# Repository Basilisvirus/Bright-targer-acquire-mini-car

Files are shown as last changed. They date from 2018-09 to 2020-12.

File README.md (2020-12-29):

# Bright-targer-acquire-mini-car
This project is written in greek.

A mini battery-runned car that avoids obstacles and follows the brighter light-emitting source simultaneously. 

https://drive.google.com/open?id=1Uj9xmuziskHSL8KATfDlSYlBZ7Kqk1FP

Having any issues with the project? email me: christianidis@disroot.org

Κατασκέυασα & προγραμμάτισα αυτοκινούμενο μικρό όχημα η κίνηση του οποίου ελέγχεται από  μικρουπολογιστή atmega328p. Αποφεύγει εμπόδια και ταυτόχρονα κινειται στη πιο φωτεινή πηγή

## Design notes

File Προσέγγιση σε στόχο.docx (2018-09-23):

Manual…………………………………………………….………….6

# Christianidis Vasileios

# basilisvirus@hotmail.com

# Η κατασκευή

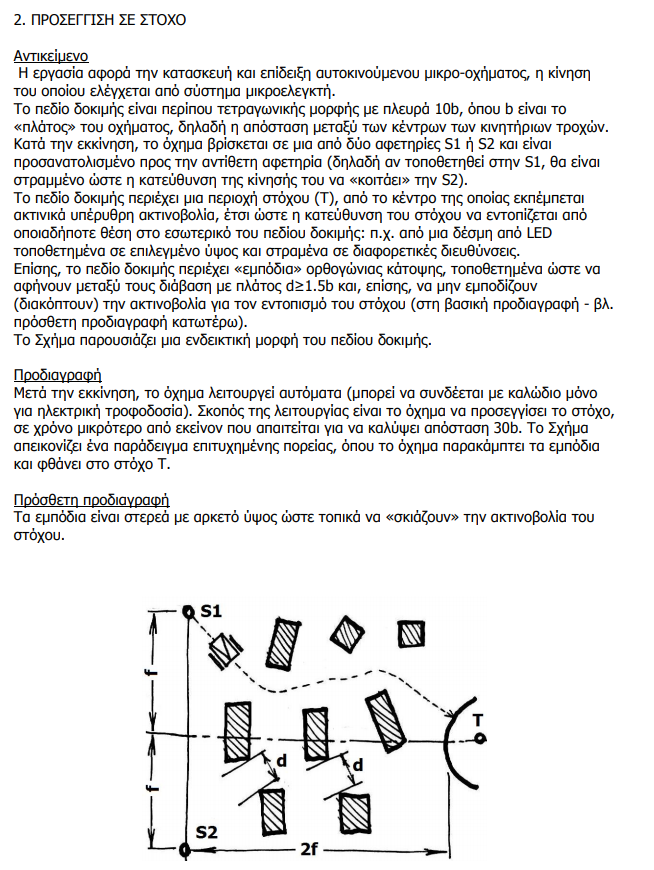
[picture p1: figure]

# Hardware

Σημείωση: δε θα παραθέτω links για datasheetsσε αυτό το αρχείο.

- Ο κώδικας, το schematic και τα sources μπορουν να βρεθούν εδώ: https://1drv.ms/f/s!Amo8HTWu_uS8hRjVVsb1Y_wef7Os αλλά θα παρασταθούν και σε αυτο το document.
- Για το σασί χρησιμοποιήθηκαν τα 3d printed open source σχέδια από αυτή την ιστοσελίδα: https://www.thingiverse.com/thing:739024/#files
- Για ρόδες, μαζί με 4 dc motors with gears χρησιμοποιήθηκαν:

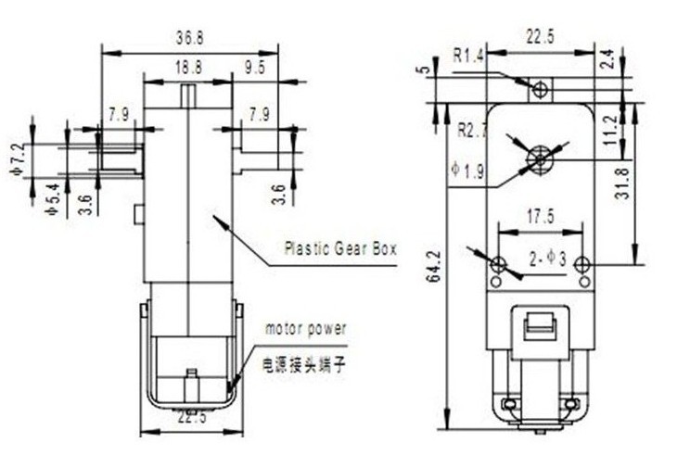
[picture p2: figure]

Motors with gears

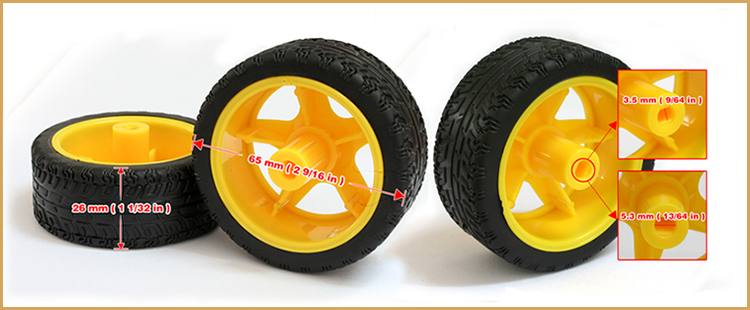
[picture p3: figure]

Wheels

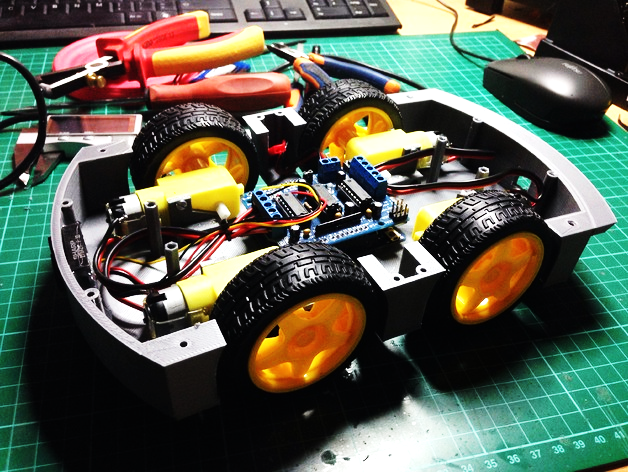
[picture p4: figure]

Ετσι δείχνει στο τέλος η κατασκευή.

- Για τους αισθητήρες απόστασης χρησιμοποίησα τρεις HC-SR04, των οποίων το datasheet μπορεί να βρεθεί εύκολα.
- Για τους αισθητήρες του στόχου χρησιμοποίησα τρία 3mm ir receivers, των οποίων το σχηματικό σύνδεσης δεν φένεται σε κάποιο datasheet οπότε πειραματίστηκα και το βρήκα μόνος μου:

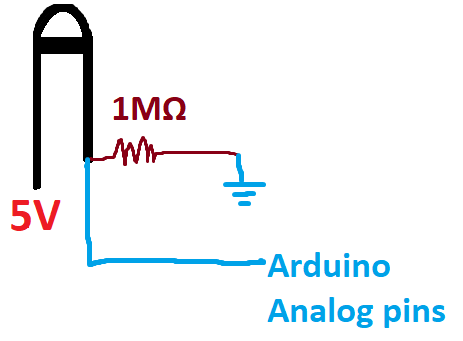
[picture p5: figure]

Από ότι καταλαβαίνετε, το χρησιμοποιούμε σαν αντίσταση για να φτιάξουμε διαιρέτη τάσης.

Να σημειωθεί ότι αυτά τα receivers ‘βλέπουν’ σε μια περιορισμένη γωνία μπροστά τους και όχι από οποιαδήποτε κατεύθυνση ‘πέσει το ir φως επάνω τους. Περισσότερες πληροφορίες μπορείτε να δείτε στο datasheet.

- Θα χρειαστεί επίσης ένας Atmega για να φορτωθεί και να λειτουργήσει ο κώδικας που έφτιαξα.
- Κατά τη συναρμολόγηση προτείνω να χρησιμοποιηθούν βίδες με παξιμάδια και κόλλα συλικόνης μετά το βίδωμα για καλύτερο κράτημα των βιδών πάνω στο σασί.
- Θα χρειαστούν ενα l293d για τον έλεγχο δύο από τις 4 ρόδες, καθώ το Arduino δεν εχει αρκετα πινς για να υποστηρίξει όλες τις ρόδες (μαζί με τους αισθητήρες απόστασης και στόχου). Επίσης η χρήση και των 4ρων motor, θα εκανε τη κίνηση του αυτοκινούμενου οχληματος πιο γρήγορη και ίσως λιγότερη σταθερή και πιο δύσκολα ελέγξιμη. Ενα επιπλεόν πλεονέκτημα σε αυτό, ειναι οτι μειώνεται η περιπλοκότητα του κώδικα.

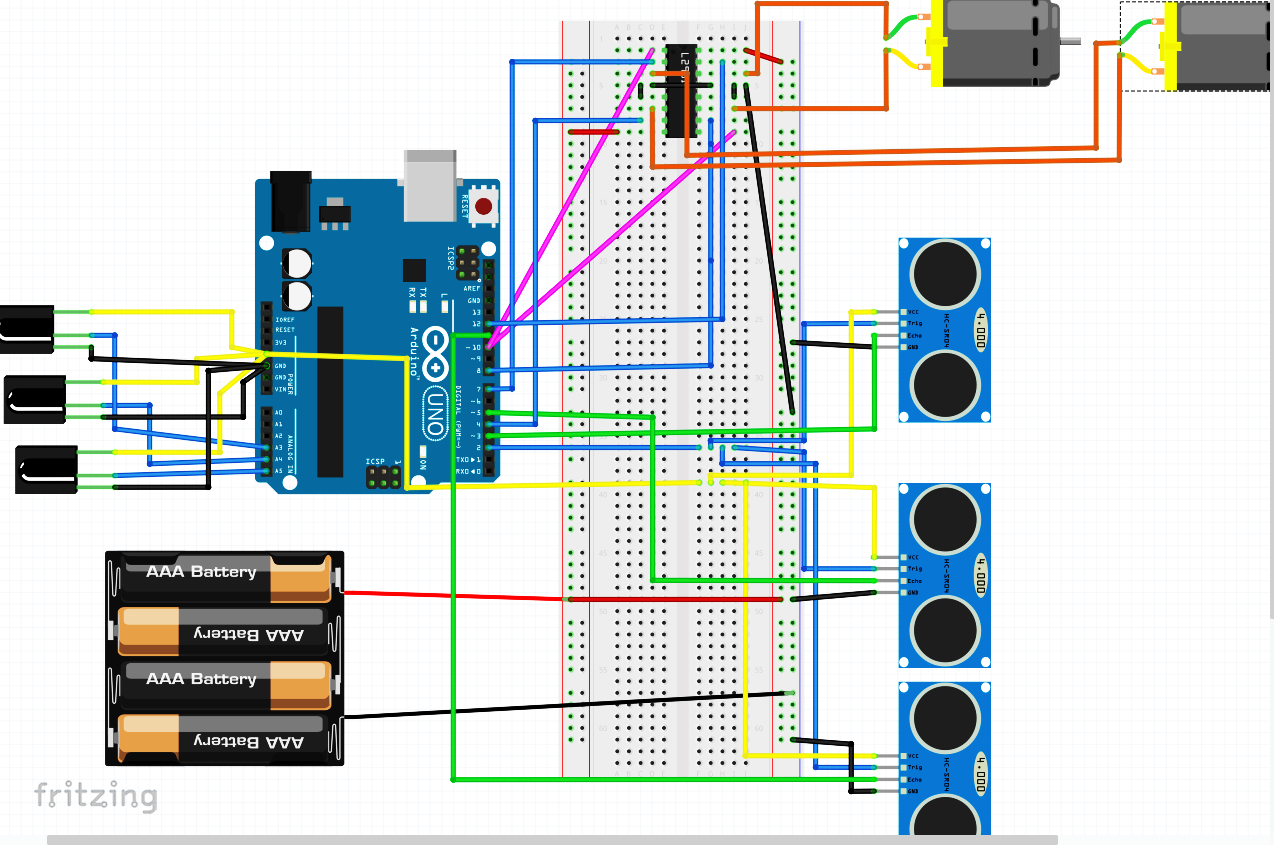
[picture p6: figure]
Uhntitled

# Schematic

https://drive.google.com/open?id=1Ohjf8QqbuifDqxd8q5MsjFSMyy_xZTs9

# Περιληπτικά κομμάτια του σασί

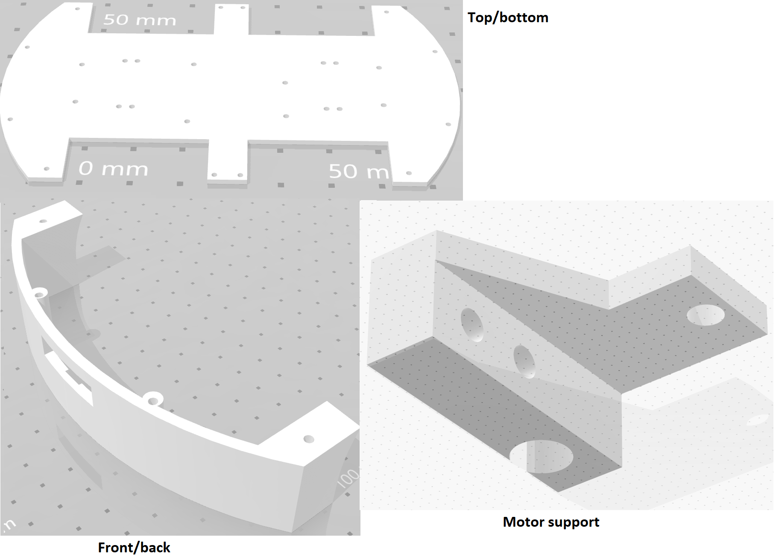
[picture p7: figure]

Πηγαίος Κώδικας/ Source code

https://drive.google.com/open?id=1fHzmqZWmkc9tEwT3Mwv_I1fpjDwS4EbD

# Περίληψη προγράμματος

Το πρόγραμμα υλοποιεί τη λειτουργία του αυτοκινουμένου οχήματος ως εξής:

α)την κίνηση των τροχών του

Εδώ, αξίζει να σημειωθεί ότι δεν χρησιμοποιήθηκαν όλοι οι τροχοί, (4 τροχοί), αλλά μόνο οι δυο πίσω. Για αυτό, το πρόγραμμα περιέχει σχόλια από το αρχικό πρόγραμμα, το οποίο χρησιμοποιούσε και τις 4 ρόδες, μαζί με το motor control ic circuit. Αυτά τα σχόλια μπορούν να διαγραφούν με ασφάλεια.

β)Η κύρια συνάρτηση που κινεί τους τροχούς είναι η void Move(int xwheel, int ywheel, bool forward). Η οποία ως πρώτη και δεύτερη μεταβλητή παίρνει τις ρόδες η την ρόδα που θέλουμε να κινήσουμε (ρόδα 3 είναι η πίσω δεξιά, ενώ ρόδα 4 η πίσω αριστερά), ως πρώτη η δεύτερη μεταβλητή και ως τρίτη η forward, η οποία αν είναι true, η/οι αντίστοιχες ρόδες/-α θα κινηθεί μπροστά. Αν είναι false, θα κινηθεί πίσω.

γ)Την μέτρηση της απόστασης σε εκατοστά των αισθητήρων απόστασης που έχει (μπροστά αριστερά, μπροστά δεξιά και μπροστά ευθεία)

Εδώ χρησιμοποιείται η συνάρτηση int Distance(char PinNum), η οποία παίρνει ως παράμετρο ,τον αισθητήρα απόστασης ο οποίος θα χρησιμοποιηθεί για να μετρηθεί η απόσταση. (‘r’ για το δεξί αισθητήρα, ‘l’ για τον left αισθητήρα και ‘m’ για τον μεσαίο αισθητήρα. Να σημειωθεί ότι τα triggers των αισθητήρων είναι κοινά. Δεν έχει αρκετά pins το uno για να βάλω ξεχωριστά triggers. Κάθε φορά που θέλω να πάρω μέτρηση μέσω της συνάρτησης για την απόσταση, η συνάρτηση Distance στέλνει παλμό (trigger) σε όλους τους αισθητήρες, όμως αντίστοιχα με το ποιο αισθητήρα θέλω να δω την έξοδο του (echo),αυτουνού τη τιμή παίρνω, παρόλο που τους ενεργοποιώ όλους με τη trig. Αυτό δεν φαίνεται να επηρεάζει τις μετρήσεις μετά από κάποιους πειραματισμούς που έκανα.

δ)Την μέτρηση της δύναμης του υπεριώδους (infrared) φωτός που λαμβάνει από τους τρεις αισθητήρες infrared φωτός που έχει, ο κάθε ένας αισθητήρας ir είναι κάτω από το αντίστοιχο αισθητήρα απόστασης.

ε)Η συνάρτηση int Av_sens(char sens, int M=20) παίρνει έναν αισθητήρα ως πρώτη παράμετρο (l,r,m) όπως και με τους αισθητήρες απόστασης. Επίσης παίρνει μια τιμή Μ σαν παράμετρο, η οποία δείχνει πόσες τιμές θα πάρει σαν δείγμα για να βγάλει το μέσο ορό των μετρήσεων Μ που πηρέ. Επιστρέφει μια τιμή αναμεσά στο 0-1023

ζ)Τη βαθμονόμηση της ποσότητας του ir φωτισμού που δέχεται (με τον στόχο αναμένον και με το στόχο σβηστό) για να καθορίσει τη φωτεινότητα του δωμάτιου και τη φωτεινότητα του στόχου σε σχέση με το δωμάτιο.

Τέλος, συνδυάζει όλα τα παραπάνω στη void loop για να κινηθεί στο χώρο και να προσεγγίσει το στόχο.

Manual

Σχετικά με τη τελευταία λειτουργία του αυτοκινουμένου οχήματος (λειτουργία 4), για τη χρήση του οχήματος πρέπει να τοποθετείται το όχημα στο δωμάτιο κοιτώντας τη πιο φωτεινή πλευρά του, η οποία καλό είναι να είναι όσο πιο σκοτεινή γίνεται. Με τα ir leds σβηστά, μόλις πάρει την ένδειξη του φωτισμού, θα φανεί στο serial monitor. Υστέρα θα περιμένει περίπου 6 sec, για να ανάψουμε τα ir leds και θα πάρει τη δεύτερη μέτρηση. Ύστερα εφόσον οι δεύτερες μετρήσεις είναι > από τις πρώτες, θα ξεκινήσει να κινείται προς τον στόχο και να αποφεύγει τα εμπόδια

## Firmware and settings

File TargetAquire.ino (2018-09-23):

//some lines are commented out to disable wheels 1,2 in order to have enugh pins for distance measurement.
int Br_Preset=500;    //set the acceptable 'amount of' brightness in the room.(1024 is the max the sensor can read)
int Obstacle_Dist=20;
//Enable for wheels 1,2
//int En_1_2=2;
//Enable for wheels 3,4
int En_3_4=10;

//FIRST L293D
//int Wheel_1_1=5;//wheel 1_1
//int Wheel_1_2=3;//wheel 1_2

//int Wheel_2_1=6;//wheel 2_1
//int Wheel_2_2=9;//wheel 2_2

//SECOND L293D
int Wheel_3_1=4;//wheel 3_1
int Wheel_3_2=7;//wheel 3_2

int Wheel_4_1=8;//wheel 4_1
int Wheel_4_2=12;//wheel 4_2

//Distance sensors
const int TrigAll= 2;//i will use one pin to trigger them all together
const int EchoLeft=11;
const int EchoMid=5;
const int EchoRight=3;
//Distance variables
long duration;
int distance;

//Distance and last move (right/left) variables
char LastMov='n';
char Last_Ir=0;

int    Cur_Dist_M;
int    Cur_Dist_L;
int    Cur_Dist_R;

//declaring the names where the ir sensor readings are stored, and others for all the functions of ir

//Minimum ir sensor readings (without ir transmitters)
int RightSensMin;
int MidSensMin;
int LeftSensMin;
//============================================================
int i;
//=============================================================
//variables that help the function of the function Av_Sens
int SensAdd=0, Sens=0;
//=============================================================
//Error for hight brighness
bool BrightError=true;
bool Calibration=false;


//============================================================
//if ir receiver is >= than these, the target will be in sight
int LeftSensMax=0;
int RightSensMax=0;
int MidSensMax=0;
//============================================================
//Sweet spots
int MidSweetSpot,LeftSweetSpot, RightSweetSpot;

//These will change each time they take a different sample:
int MidReading, LeftReading, RightReading;

//===========================================================================================================


//function to stop all the wheels at once========================================================================
void Break(){
//  digitalWrite(Wheel_1_1,0);
//  digitalWrite(Wheel_1_2,0);
//  digitalWrite(Wheel_2_1,0);
//  digitalWrite(Wheel_2_2,0);
  digitalWrite(Wheel_3_1,0);
  digitalWrite(Wheel_3_2,0);
  digitalWrite(Wheel_4_1,0);
  digitalWrite(Wheel_4_2,0);
//  digitalWrite(En_1_2,0);
  digitalWrite(En_3_4,0);
}


//Function to move the desired two wheels forward or backward========================================================================
void Move( int XWheel, int YWheel=0,bool forward=1){
  //first make sure aall wheels are stationary (due to hardware bug);
//  digitalWrite(En_1_2,0);
  digitalWrite(En_3_4,0);
  
 //enable the wheels we want to move
// if (XWheel==1 || YWheel==2 || XWheel==2 || YWheel==1){
//  digitalWrite(En_1_2,1);
// }

 if(XWheel==3 || XWheel==4 || YWheel==3 || YWheel==4){
    digitalWrite(En_3_4,1);
 }

  //if we pick wheel 1 in any case, make the forward move for wheel 1
   if((XWheel==1) || (YWheel==1)){
//digitalWrite(Wheel_1_1,forward);
//digitalWrite(Wheel_1_2,!forward);
  }
    //if we pick wheel 2 in any case, make the forward move for wheel 2
  if((XWheel==2) || (YWheel==2)){
//digitalWrite(Wheel_2_1,forward);
//digitalWrite(Wheel_2_2,!forward);
  }

  if((XWheel==3) ||(YWheel==3)){
digitalWrite(Wheel_3_1,forward);
digitalWrite(Wheel_3_2,!forward);
  }

    if((XWheel==4) ||(YWheel==4)){
digitalWrite(Wheel_4_1,!forward);
digitalWrite(Wheel_4_2,forward);
  }
}


//================================================================================================
int Distance(char PinNum){

  digitalWrite(TrigAll,0);
  delayMicroseconds(3);
  //set the trigpin on high for 10 microseconds
  digitalWrite(TrigAll,1);
  delayMicroseconds(12);
  digitalWrite(TrigAll,0);

 if (PinNum=='l'){
duration=pulseIn(EchoLeft,1);
 }
 else if(PinNum=='m'){
duration=pulseIn(EchoMid,1);
 }
 else if(PinNum=='r'){
duration=pulseIn(EchoRight,1);
 }

  //distance calc
return duration*0.017;
  delay(50);
}


//====================Function to avoid obstacles=====================================================================
void Avoid_Obs(){
    Cur_Dist_M=Distance('m');
    Cur_Dist_L=Distance('l');
    Cur_Dist_R=Distance('r');
    
if(Cur_Dist_M<=Obstacle_Dist && Cur_Dist_L>Obstacle_Dist && Cur_Dist_R>Obstacle_Dist){
 if (Last_Ir=='l'){
        Serial.println("Moving left due to the last move left");
        do{
      Move(4,0,0);
      Move(3);
       Cur_Dist_M=Distance('m');
        }while(Cur_Dist_M<=Obstacle_Dist);
 }
 else if(Last_Ir=='r'){
         Serial.println("Moving right due to the last move right");
        do{
         Move(4);
         Move(3,0,0);
         Cur_Dist_M=Distance('m');
        }while(Cur_Dist_M<=Obstacle_Dist);
 }
 Break();
}

if(Cur_Dist_L<=Obstacle_Dist){
    Serial.println("left<=20");
  Break();
   Cur_Dist_L=Distance('l');
  while(Cur_Dist_L<=Obstacle_Dist){
      Move(4);
      Move(3,0,0);
      delay(500);
     Cur_Dist_L=Distance('l');
     Serial.println("left<=20");
  }
         LastMov='r';
  Move(3,4);
  Serial.println("Moving bit forward");
  delay(400);
  Break();
}

if(Cur_Dist_R<=Obstacle_Dist){
  Serial.println("right<=20");
    Break();
 Cur_Dist_R=Distance('r');
  while(Cur_Dist_R<=Obstacle_Dist){
      Move(4,0,0);
      Move(3);
      delay(500);
  Cur_Dist_R=Distance('r');
   Serial.println("right<=20");
  }
    LastMov='l';
    Move(3,4);
    Serial.println("Moving bit forward");
  delay(400);
  Break();
}
Serial.println("End of Avoid_obs()");
}

//============================Av_Sens=================================================================================================
//average measurement of a 'c' ir sensor
int Av_Sens(char c, int M=20){
  SensAdd=0;//setting SensAdd to 0 so next time the function is called, it wont use previews measures
  //calibrate for the selected ir sensor
for (i=0; i<=M; i++){ //M measurements for the c sensor
  if(c=='r'){
    Sens=analogRead(A5);
  }
  else if(c=='l'){
    Sens=analogRead(A3);
  }
  else if(c=='m'){
    Sens=analogRead(A4);
  }
delay(10);
SensAdd=SensAdd + Sens;
}
return SensAdd/M;//return the average of the readings
}


//===========================Br_Level======================================================================================================
//Brightness level, gives BrightError=true or false
void Br_LevelCheck(){
  Serial.println("Dont stand in front of the sensors, turn off the ir transmitter and the lights");
 delay(10000);
  LeftSensMin=Av_Sens('l');
MidSensMin=Av_Sens('m');
RightSensMin=Av_Sens('r');

if(LeftSensMin>Br_Preset || RightSensMin>Br_Preset || MidSensMin>Br_Preset){
 Serial.println("Room is too bright");
  Serial.print("LeftSensMin= ");
 Serial.println(LeftSensMin);
 Serial.print("MidSensMin= ");
 Serial.println(MidSensMin);
 Serial.print("RightSensMin= ");
 Serial.println(RightSensMin);
 BrightError=true; 
}
else {
   Serial.println("Brightness level passed");
  Serial.print("LeftSensMin= ");
 Serial.println(LeftSensMin);
 Serial.print("MidSensMin= ");
 Serial.println(MidSensMin);
 Serial.print("RightSensMin= ");
 Serial.println(RightSensMin);
  BrightError=false;
}
//calibrating
if (BrightError==false){
  Serial.println("Turn on ir transmitter and maintain maximum distance,facing directly the front ir receiver");
  delay(6000);
LeftSensMax=Av_Sens('l');
MidSensMax=Av_Sens('m');
RightSensMax=Av_Sens('r');

if(LeftSensMax>LeftSensMin && MidSensMax>MidSensMin && RightSensMax>RightSensMin){
 Serial.println("Calibrating done");
  Serial.print("LeftSensMax= ");
 Serial.println(LeftSensMax);
 Serial.print("MidSensMax= ");
 Serial.println(MidSensMax);
 Serial.print("RightSensMax= ");
 Serial.println(RightSensMax);
 Calibration=true;
}
else{
  Calibration=false;
  Serial.println("Did not detect any change on light or ir transmitter");
  Serial.print("LeftSensMax= ");
 Serial.println(LeftSensMax);
 Serial.print("MidSensMax= ");
 Serial.println(MidSensMax);
 Serial.print("RightSensMax= ");
 Serial.println(RightSensMax);
  }
}//DONE IF BRIGHTERROR==TRUE

if (Calibration==true){//this means all tests passed, time to set up the sweet spot
  //if the corresponding sensor value is > than the sweet spot, it is within sight
  LeftSweetSpot= (LeftSensMax+ LeftSensMin)/2 ;
   MidSweetSpot= (MidSensMax+ MidSensMin)/2 ;
  RightSweetSpot= (RightSensMax+ RightSensMin)/2 ;


  Serial.println("Sweet spots: ");
  Serial.print("LeftSweetSpot= ");
  Serial.println(LeftSweetSpot);
  Serial.print("MidSweetSpot= ");
  Serial.println(MidSweetSpot);
  Serial.print("RightSweetSpot= ");
  Serial.println(RightSweetSpot);
}

}




//=========================setup==============================================================================================
void setup() {
  Serial.begin(9600);
pinMode(TrigAll,OUTPUT);
pinMode(EchoRight,INPUT);
pinMode(EchoLeft,INPUT);
pinMode(EchoMid,INPUT);

  //all the wheels
//pinMode( Wheel_1_1,OUTPUT);
//pinMode( Wheel_1_2,OUTPUT);
//pinMode( Wheel_2_1,OUTPUT);
//pinMode( Wheel_2_2,OUTPUT);

pinMode( Wheel_3_1,OUTPUT);
pinMode( Wheel_3_2,OUTPUT);
pinMode( Wheel_4_1,OUTPUT);
pinMode( Wheel_4_2,OUTPUT);

//pinMode(En_1_2, OUTPUT);
pinMode(En_3_4, OUTPUT);

//digitalWrite(En_1_2,0);
digitalWrite(En_3_4,0);
delay(100);

//check the brightness level start:
Br_LevelCheck();

}


//========================loop==============================================================================================
void loop() {
  
if (Calibration==true){
  
  do{
    MidReading=Av_Sens('m',1);
    LeftReading= Av_Sens('l',1);
    RightReading=Av_Sens('r',1);
    Serial.print("MidReading= ");
    Serial.println(MidReading);
    
    Serial.print("LeftReading= ");
    Serial.println(LeftReading);
    
    Serial.print("RightReading= ");
    Serial.println(RightReading);
    
  if (MidReading>MidSweetSpot){
    Move(3,4);
    Avoid_Obs();
    Serial.println("Moving forward/avoiding obstacles");
  }
  else if(RightReading>RightSweetSpot && RightReading>LeftReading){
    Last_Ir='r';
    Break();
    do{
      Serial.println("Moving right due to sweet spot");
      Move(3,0,0);
      Move(4);
      MidReading= Av_Sens('m',1);
      LeftReading= Av_Sens('l',1);
    }while(MidReading<=MidSweetSpot || LeftReading<=LeftSweetSpot);
  }
  else if(LeftReading> LeftSweetSpot && LeftReading>=LeftSweetSpot){
    Last_Ir='l';
    Break();
    do{
    Serial.println("Moving left due to sweet spot");
      Move(3);
      Move(4,0,0);
      MidReading= Av_Sens('m',1);
      RightReading=Av_Sens('r',1);
    }while(MidReading<=MidSweetSpot || RightReading<=RightSweetSpot);
  }
}  while(1);//END OF DO WHILE(1)

}//END OF IF CALIBRATION==TRUE

}//END OF LOOP
